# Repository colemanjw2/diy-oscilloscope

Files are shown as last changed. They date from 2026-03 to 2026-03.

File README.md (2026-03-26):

#  DIY Cathode-Ray Tube Oscilloscope (2AP1A)

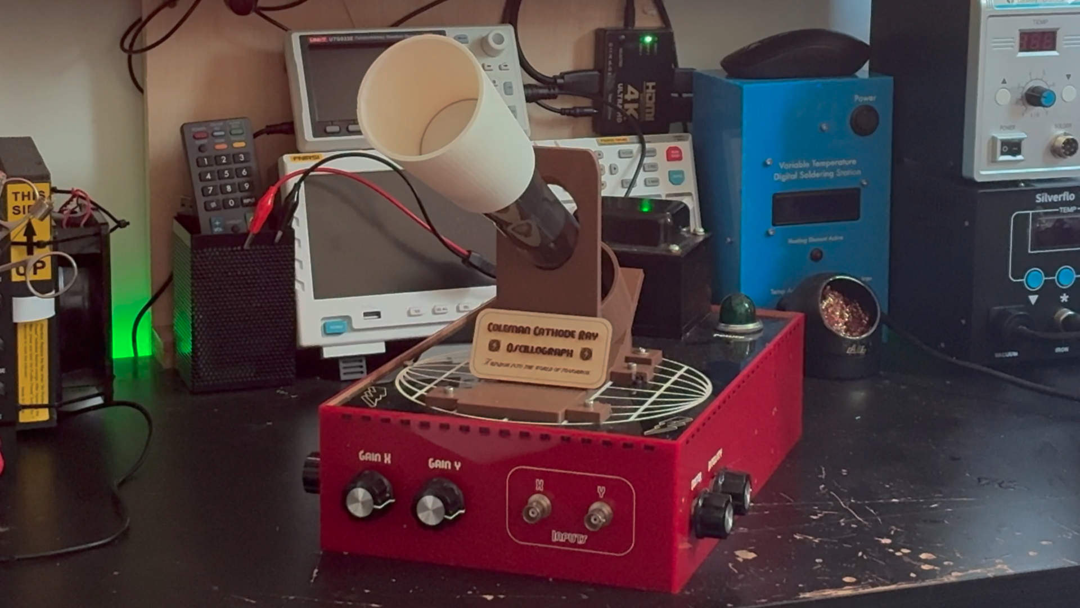
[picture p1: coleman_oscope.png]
A DIY CRT Oscilloscope


A fully discrete, high-voltage, electrostatic CRT oscilloscope built from first principles.

This project recreates the fundamental operation of early oscilloscopes using a vacuum tube, analog deflection amplifiers, and a high-voltage supply — with no digital processing, sampling, or abstraction.

It is based on the designs found here:

https://web.archive.org/web/20120718013731/http://mysite.du.edu/~etuttle/electron/elecindx.htm

And it is specifically this project:

https://web.archive.org/web/20120714102433/http://mysite.du.edu/~etuttle/electron/elect29.htm

Because the college that once hosted this site has decided to no longer do so, one must use WayBack Machine to view but I have also put the full webpage in a folder inside of this repo. 

---

## Overview

This oscilloscope is based around the **2AP1A cathode-ray tube**, a small electrostatic CRT that allows direct visualization of electrical signals through electron beam deflection.

Unlike modern oscilloscopes:
- No ADCs  
- No memory  
- No triggering system  

The display is a **real-time physical representation of voltage**.

---

##  System Architecture

The build consists of three primary subsystems:

### 1. CRT (Display Device)
- 2AP1A electrostatic CRT
- ~2" phosphor screen (P1 green, medium persistence)
- Electrostatic deflection plates (X/Y)

---

### 2. Deflection Amplifiers
- High-voltage analog amplifiers (~150–200 Vpp output)
- Drive the deflection plates directly
- Configurable for:
  - single-axis waveform display  
  - X-Y (Lissajous) mode  

---

### 3. High Voltage Power Supply
- ~700–800 V DC supply
- Low current (~1 mA total load)
- Resistive divider network for:
  - cathode bias  
  - grid control  
  - focusing  
  - anode voltages  

---

## CRT Operation (2AP1A)

Electron beam flow:

```

Cathode → Grid 1 → Anode 1 → Grid 2 → Anode 2 → Deflection Plates → Screen

```

### Functional Breakdown

| Element | Function |
|---|---|
| Cathode | Thermionic electron emission |
| Grid 1 | Intensity (beam current control) |
| Anode 1 | Pre-acceleration + beam shaping  |
| Grid 2 | Focus control (electrostatic lens) |
| Anode 2 | Main acceleration (~700–1000 V)  |
| Deflection Plates| Signal-driven beam steering |
| Screen | Phosphor emission |

---

## Lissajous Mode (X-Y Operation)

When two signals are applied:

- X-axis → horizontal deflection  
- Y-axis → vertical deflection  

The CRT draws the relationship between them.

### Example

- X = 1000 Hz  
- Y = 999 Hz  

Result:
- Slowly rotating pattern  
- Drift rate = **1 Hz difference**

---

## ⚠️ Safety

This project involves **lethal high voltage**.

- 700–1000 V DC present  
- Capacitors retain charge after power-off  

### Recommendations:
- Use the one-hand rule when probing  
- Verify discharge before handling  
- Use properly rated components  
- Do not modify wiring while powered  

---

## Experiments Enabled

- Basic waveform visualization (no timebase)  
- X-Y plotting  
- Lissajous frequency comparison  
- Beam focusing and intensity control   

---

##  Build Notes

- Derived from classic oscilloscope circuits (ARRL-era designs)
- Uses modern components where practical
- CRT mounted with custom mechanical support
- Deflection plates AC-coupled for signal input

---

##  Project Video

https://youtu.be/sQTSOFO6ceU

---

##  Purpose

This project is not about performance.

It is about understanding:

- how electrons behave in electric fields  
- how analog systems represent signals  
- how early instrumentation worked  

---

## Key Idea

```

Voltage → electric field → force → motion → visible trace

```

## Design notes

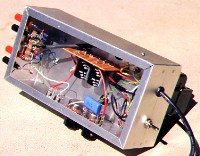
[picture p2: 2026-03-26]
Project Reference Webpage Complete/DIY CRT Oscilliscope Page_files/scopebot.jpg

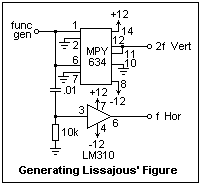
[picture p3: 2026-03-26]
Project Reference Webpage Complete/DIY CRT Oscilliscope Page_files/circ244.gif

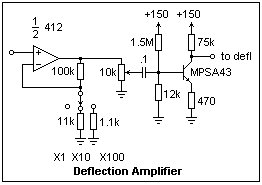
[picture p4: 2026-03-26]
Project Reference Webpage Complete/DIY CRT Oscilliscope Page_files/circ245.gif

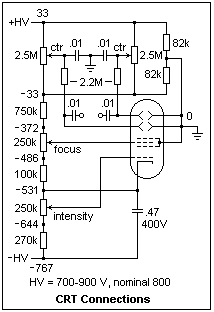
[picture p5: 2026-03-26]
Project Reference Webpage Complete/DIY CRT Oscilliscope Page_files/circ216.gif

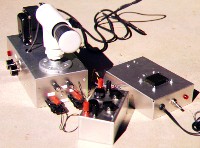
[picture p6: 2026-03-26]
Project Reference Webpage Complete/DIY CRT Oscilliscope Page_files/myscope.jpg

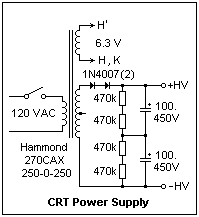
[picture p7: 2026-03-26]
Project Reference Webpage Complete/DIY CRT Oscilliscope Page_files/circ217.gif

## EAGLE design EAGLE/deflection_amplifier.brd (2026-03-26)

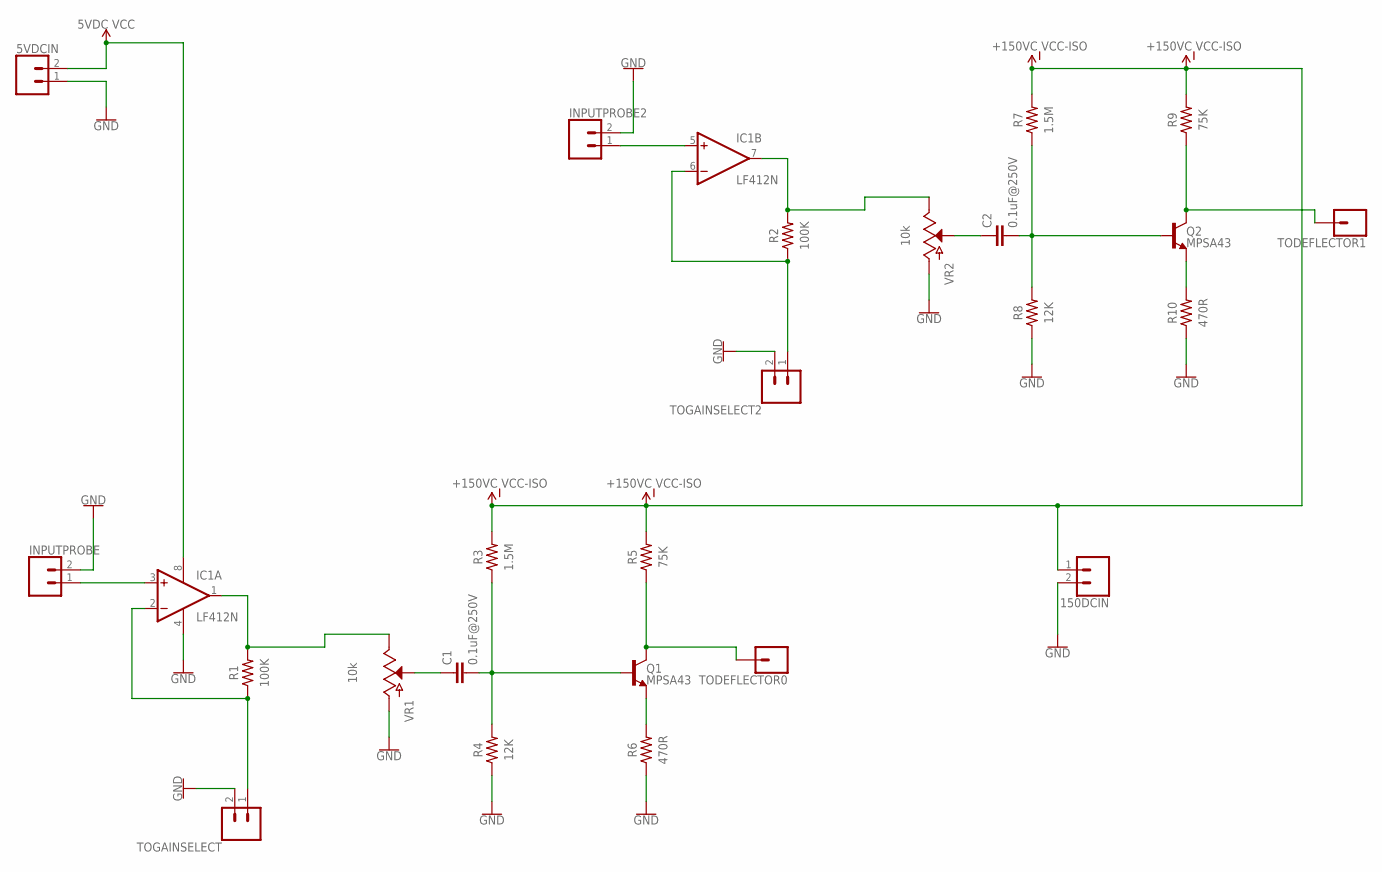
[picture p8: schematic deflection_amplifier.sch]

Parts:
5VDCIN, 150DCIN: CONN_02; 1X02
C1, C2: 0.1uF@250V; C15B8
IC1: LF412N; DIL08
INPUTPROBE, INPUTPROBE2: CONN_02; 1X02
Q1, Q2: MPSA43; TO-92
R1, R2: 100K; RESAD1176W63L850D250B
R3, R7: 1.5M; RESAD1176W63L850D250B
R4, R8: 12K; RESAD1176W63L850D250B
R5, R9: 75K; RESAD1176W63L850D250B
R6, R10: 470R; RESAD1176W63L850D250B
TODEFLECTOR0, TODEFLECTOR1: CONN_01; 1X01
TOGAINSELECT, TOGAINSELECT2: CONN_02; 1X02
VR1, VR2: 10k; POT-PTH-ALPS

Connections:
GND: 5VDCIN.1, 150DCIN.2, IC1.4 (V-), INPUTPROBE.2, INPUTPROBE2.2, R4.1, R6.1, R8.1, R10.1, TOGAINSELECT.2, TOGAINSELECT2.2, VR1.P$3 (A), VR2.P$3 (A)
unnamed: IC1.1 (OUT), R1.2, VR1.P$1 (E)
unnamed: IC1.2 (-IN), R1.1, TOGAINSELECT.1
unnamed: IC1.3 (+IN), INPUTPROBE.1
unnamed: C1.1, VR1.P$2 (S)
unnamed: C1.2, Q1.2 (B), R3.1, R4.2
unnamed: Q1.1 (E), R6.2
unnamed: Q1.3 (C), R5.1, TODEFLECTOR0.1
unnamed: IC1.7 (OUT), R2.2, VR2.P$1 (E)
unnamed: IC1.6 (-IN), R2.1, TOGAINSELECT2.1
unnamed: IC1.5 (+IN), INPUTPROBE2.1
unnamed: C2.1, VR2.P$2 (S)
unnamed: C2.2, Q2.2 (B), R7.1, R8.2
unnamed: Q2.1 (E), R10.2
unnamed: Q2.3 (C), R9.1, TODEFLECTOR1.1
VCC: 5VDCIN.2, IC1.8 (V+)
VCC-ISO: 150DCIN.1, R3.2, R5.2, R7.2, R9.2

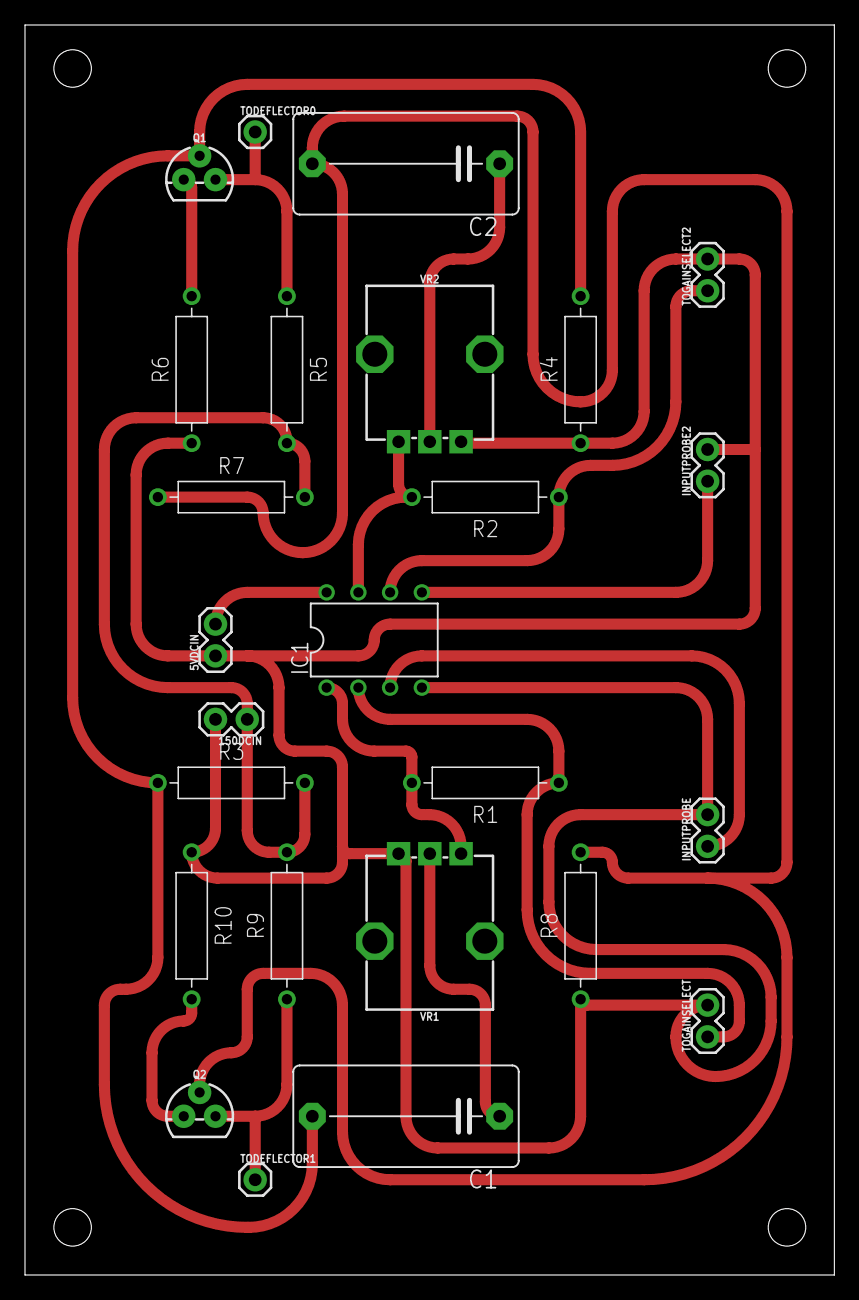
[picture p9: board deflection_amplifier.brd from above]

Board: 2 copper layers, 64.8 x 100.0 mm, 25 parts (0 on the bottom side), 17 nets.

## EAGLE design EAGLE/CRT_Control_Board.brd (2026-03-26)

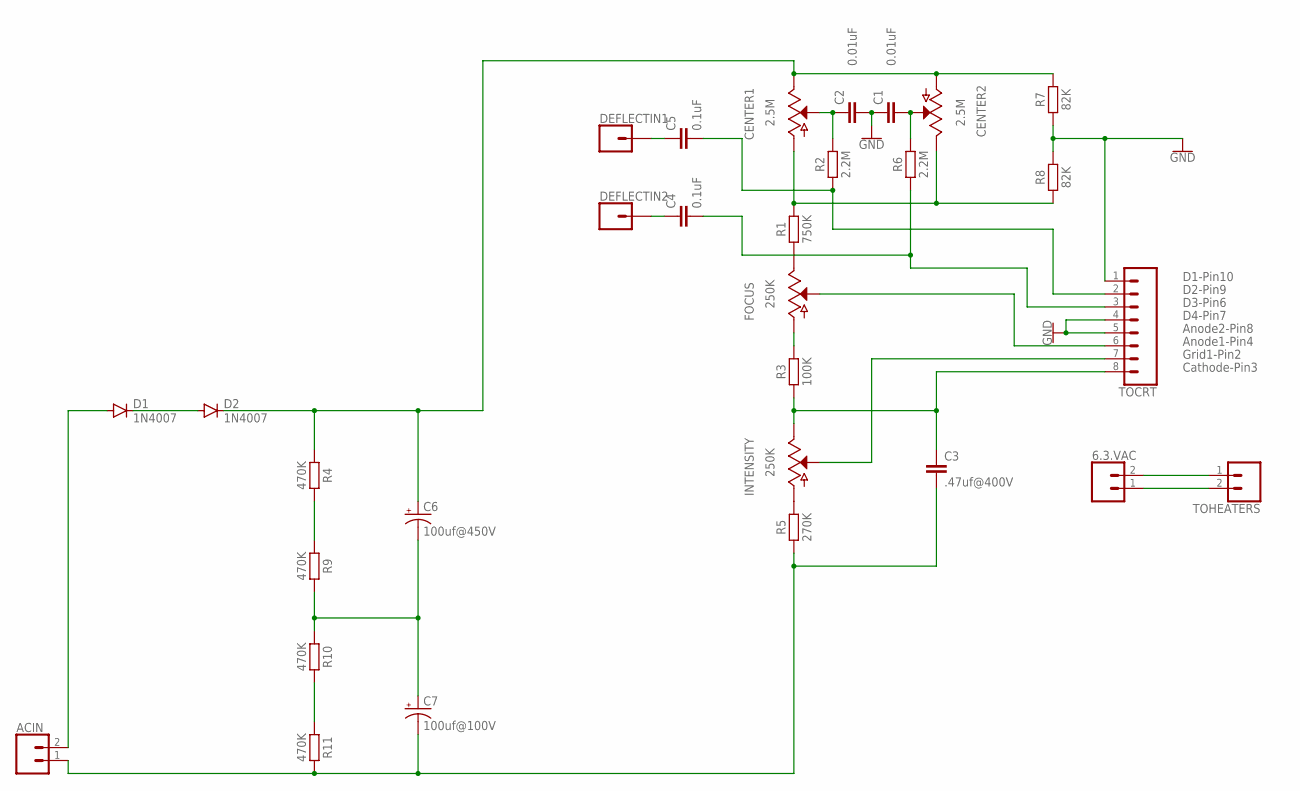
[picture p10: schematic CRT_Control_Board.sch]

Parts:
6.3.VAC: CONN_02; 1X02
ACIN: CONN_02; 1X02
C1, C2: 0.01uF; CAP-PTH-SMALL-KIT
C3: .47uf@400V; CAP-PTH-SMALL-KIT
C4, C5: 0.1uF; CAP-PTH-SMALL-KIT
C6: 100uf@450V; E5-6
C7: 100uf@100V; E5-6
CENTER1, CENTER2: 2.5M; POT-PTH-ALPS
D1, D2: 1N4007; DO41-10
DEFLECTIN1, DEFLECTIN2: CONN_01PTH_LONGPAD; 1X01_LONGPAD
FOCUS: 250K; POT-PTH-ALPS
INTENSITY: 250K; POT-PTH-ALPS
R1: 750K; RESAD1176W63L850D250B
R2, R6: 2.2M; RESAD1176W63L850D250B
R3: 100K; RESAD1176W63L850D250B
R4, R9, R10, R11: 470K; RESAD1176W63L850D250B
R5: 270K; RESAD1176W63L850D250B
R7, R8: 82K; RESAD1176W63L850D250B
TOCRT: CONN_08LONGPADS; 1X08_LONGPADS
TOHEATERS: CONN_02; 1X02

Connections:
GND: C1.1, C2.2, R7.1, R8.2, TOCRT.1, TOCRT.4, TOCRT.5
unnamed: C5.2, R2.1, TOCRT.2
unnamed: 6.3.VAC.2, TOHEATERS.1
unnamed: C6.+, CENTER1.P$1 (E), CENTER2.P$3 (A), D2.C, R4.1, R7.2
unnamed: INTENSITY.P$3 (A), R5.2
unnamed: C3.1, INTENSITY.P$1 (E), R3.1, TOCRT.8
unnamed: FOCUS.P$1 (E), R1.1
unnamed: FOCUS.P$3 (A), R3.2
unnamed: 6.3.VAC.1, TOHEATERS.2
unnamed: C4.2, R6.1, TOCRT.3
unnamed: C5.1, DEFLECTIN1.1
unnamed: C2.1, CENTER1.P$2 (S), R2.2
unnamed: C1.2, CENTER2.P$2 (S), R6.2
unnamed: FOCUS.P$2 (S), TOCRT.6
unnamed: INTENSITY.P$2 (S), TOCRT.7
unnamed: C4.1, DEFLECTIN2.1
unnamed: D1.C, D2.A
unnamed: ACIN.1, C3.2, C7.-, R5.1, R11.2
unnamed: R4.2, R9.1
unnamed: C6.-, C7.+, R9.2, R10.1
unnamed: R10.2, R11.1
unnamed: ACIN.2, D1.A
unnamed: CENTER1.P$3 (A), CENTER2.P$1 (E), R1.2, R8.1

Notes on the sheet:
D1-Pin10
D2-Pin9
D3-Pin6
D4-Pin7
Cathode-Pin3
Grid1-Pin2
Anode1-Pin4
Anode2-Pin8

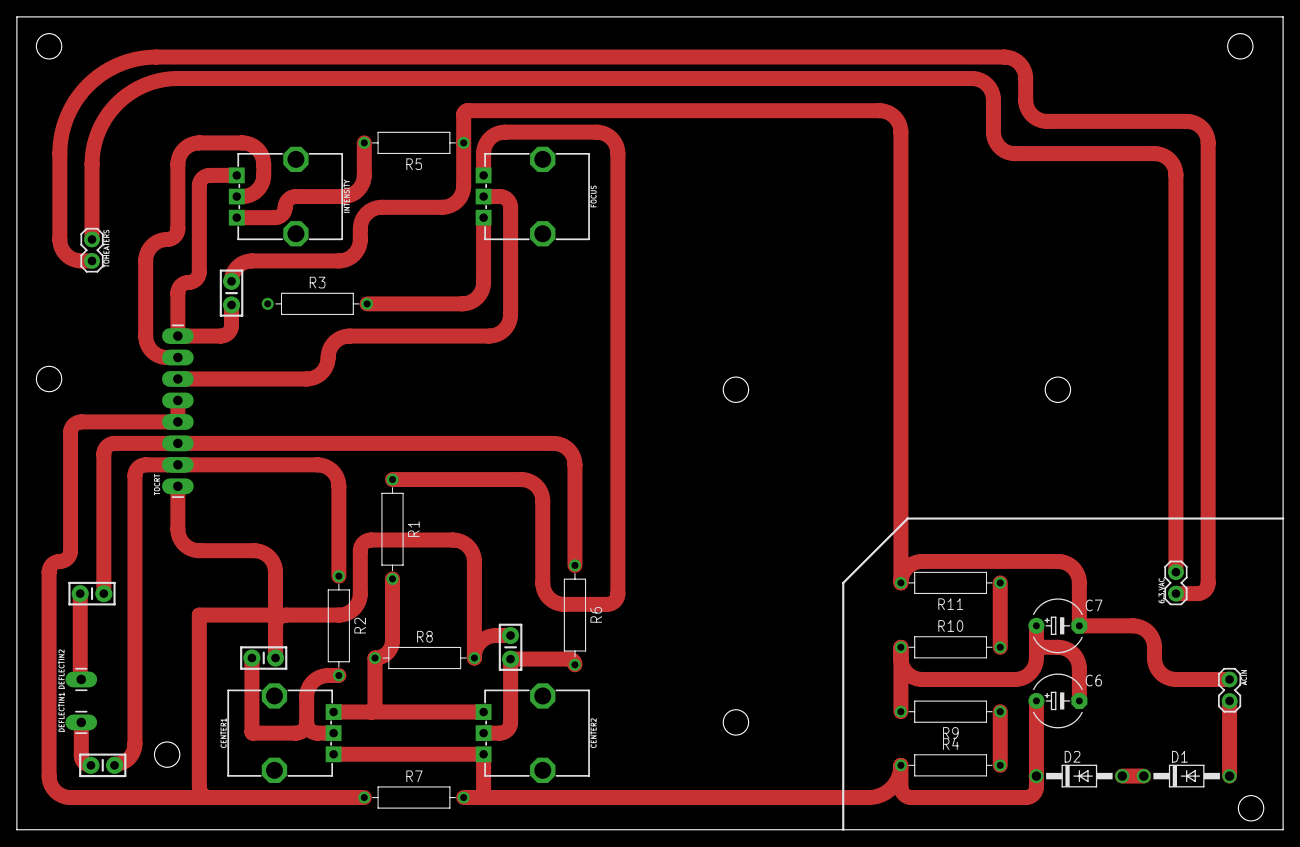
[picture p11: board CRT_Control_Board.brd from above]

Board: 2 copper layers, 149.8 x 96.2 mm, 30 parts (0 on the bottom side), 23 nets.

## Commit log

2026-03-26 Fix formatting for Voltage Distribution section
2026-03-26 Clean up README by removing outdated sections
    Removed sections on deflection physics, voltage distribution, media, and future work from README.

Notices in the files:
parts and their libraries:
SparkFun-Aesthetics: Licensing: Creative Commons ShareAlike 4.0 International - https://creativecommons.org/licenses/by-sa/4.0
